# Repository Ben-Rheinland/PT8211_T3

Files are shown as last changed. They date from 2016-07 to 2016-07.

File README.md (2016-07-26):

# PT8211_T3
This is an adapter board ("shield") for the Teensy 3.x by PJRC.<br>
It features the cheap two-channel DAC PT8211 by Princeton Technology and adds a power supply filter, an analog third order low pass filter and output buffering.
<br>
https://forum.pjrc.com/threads/29284-Dual-channel-16bit-dac-PT8211

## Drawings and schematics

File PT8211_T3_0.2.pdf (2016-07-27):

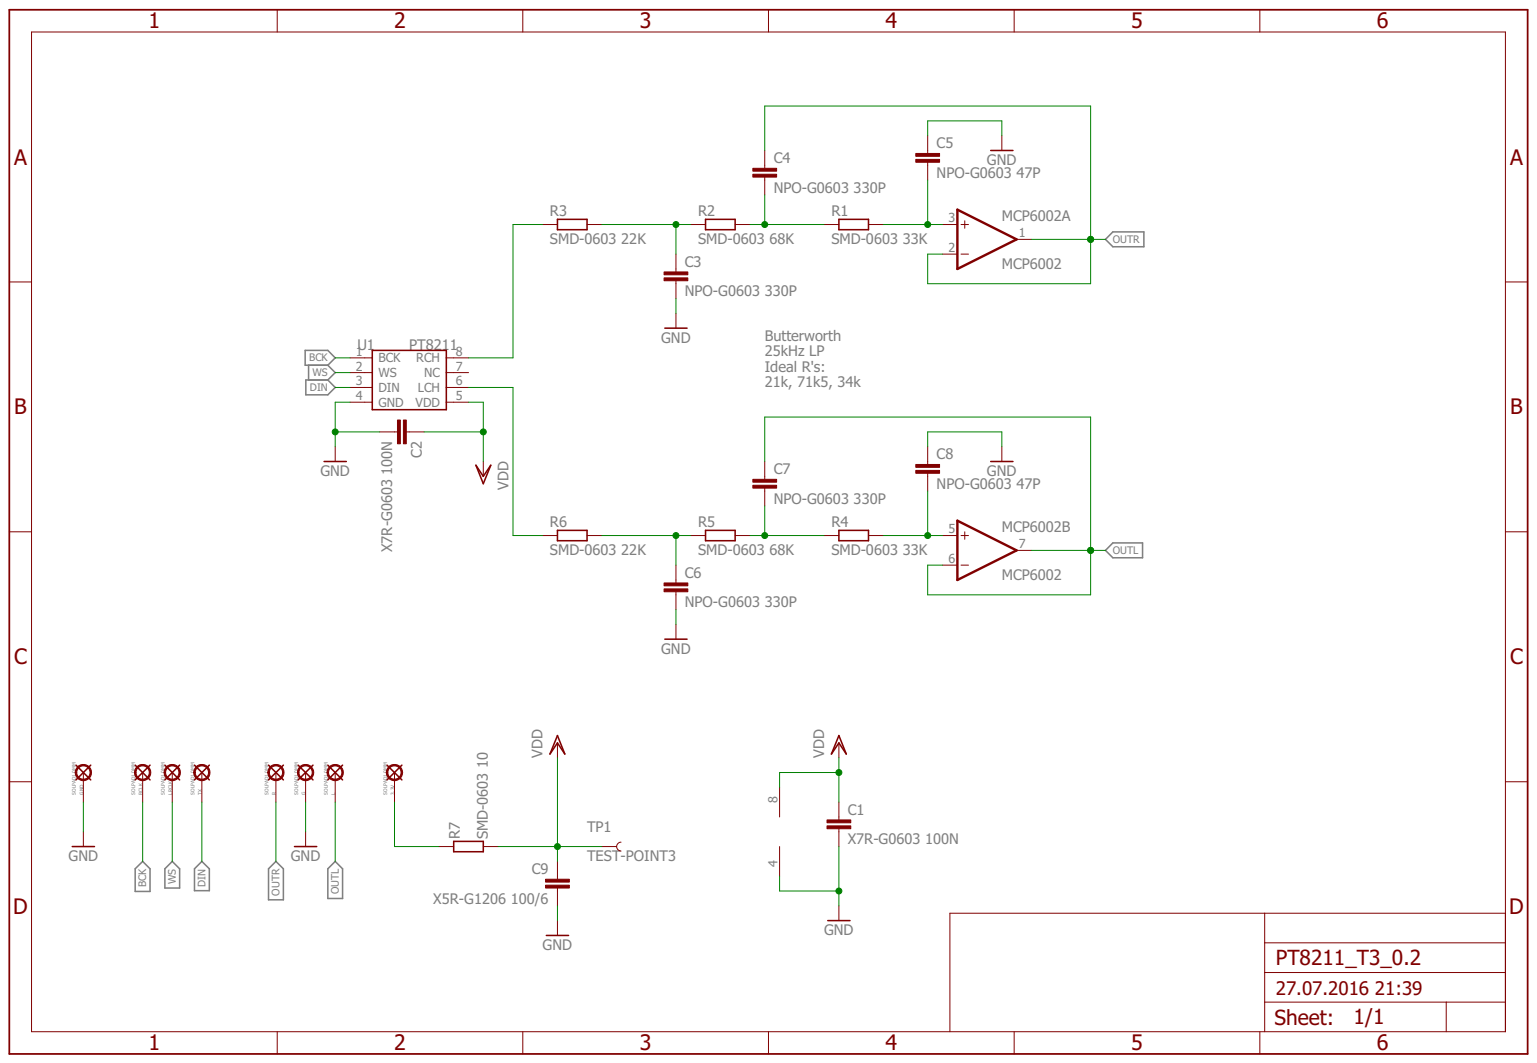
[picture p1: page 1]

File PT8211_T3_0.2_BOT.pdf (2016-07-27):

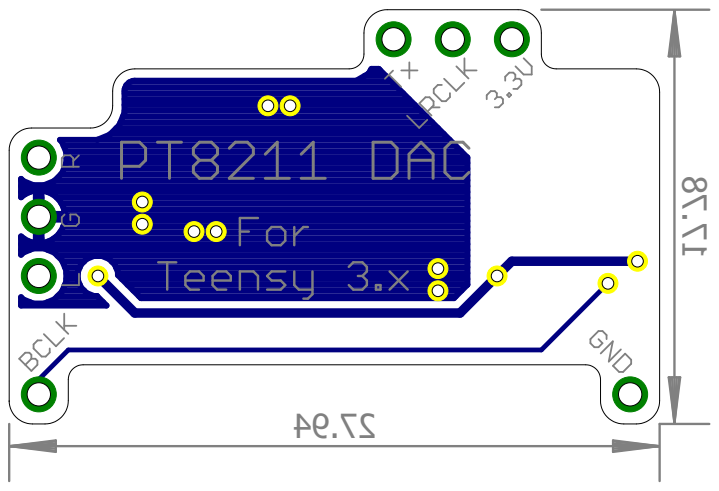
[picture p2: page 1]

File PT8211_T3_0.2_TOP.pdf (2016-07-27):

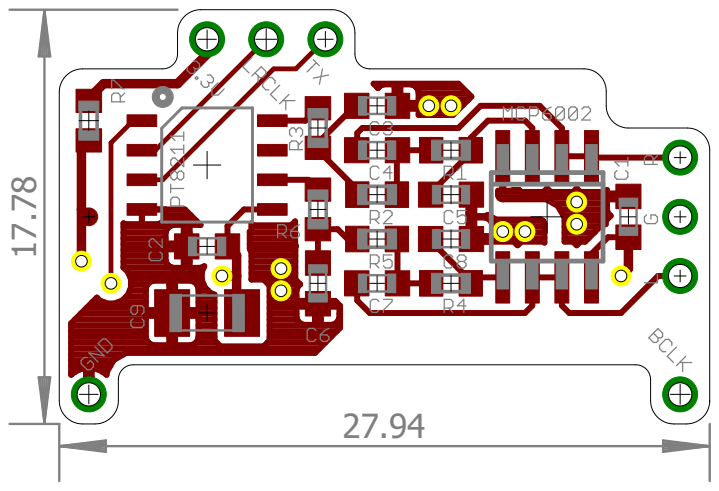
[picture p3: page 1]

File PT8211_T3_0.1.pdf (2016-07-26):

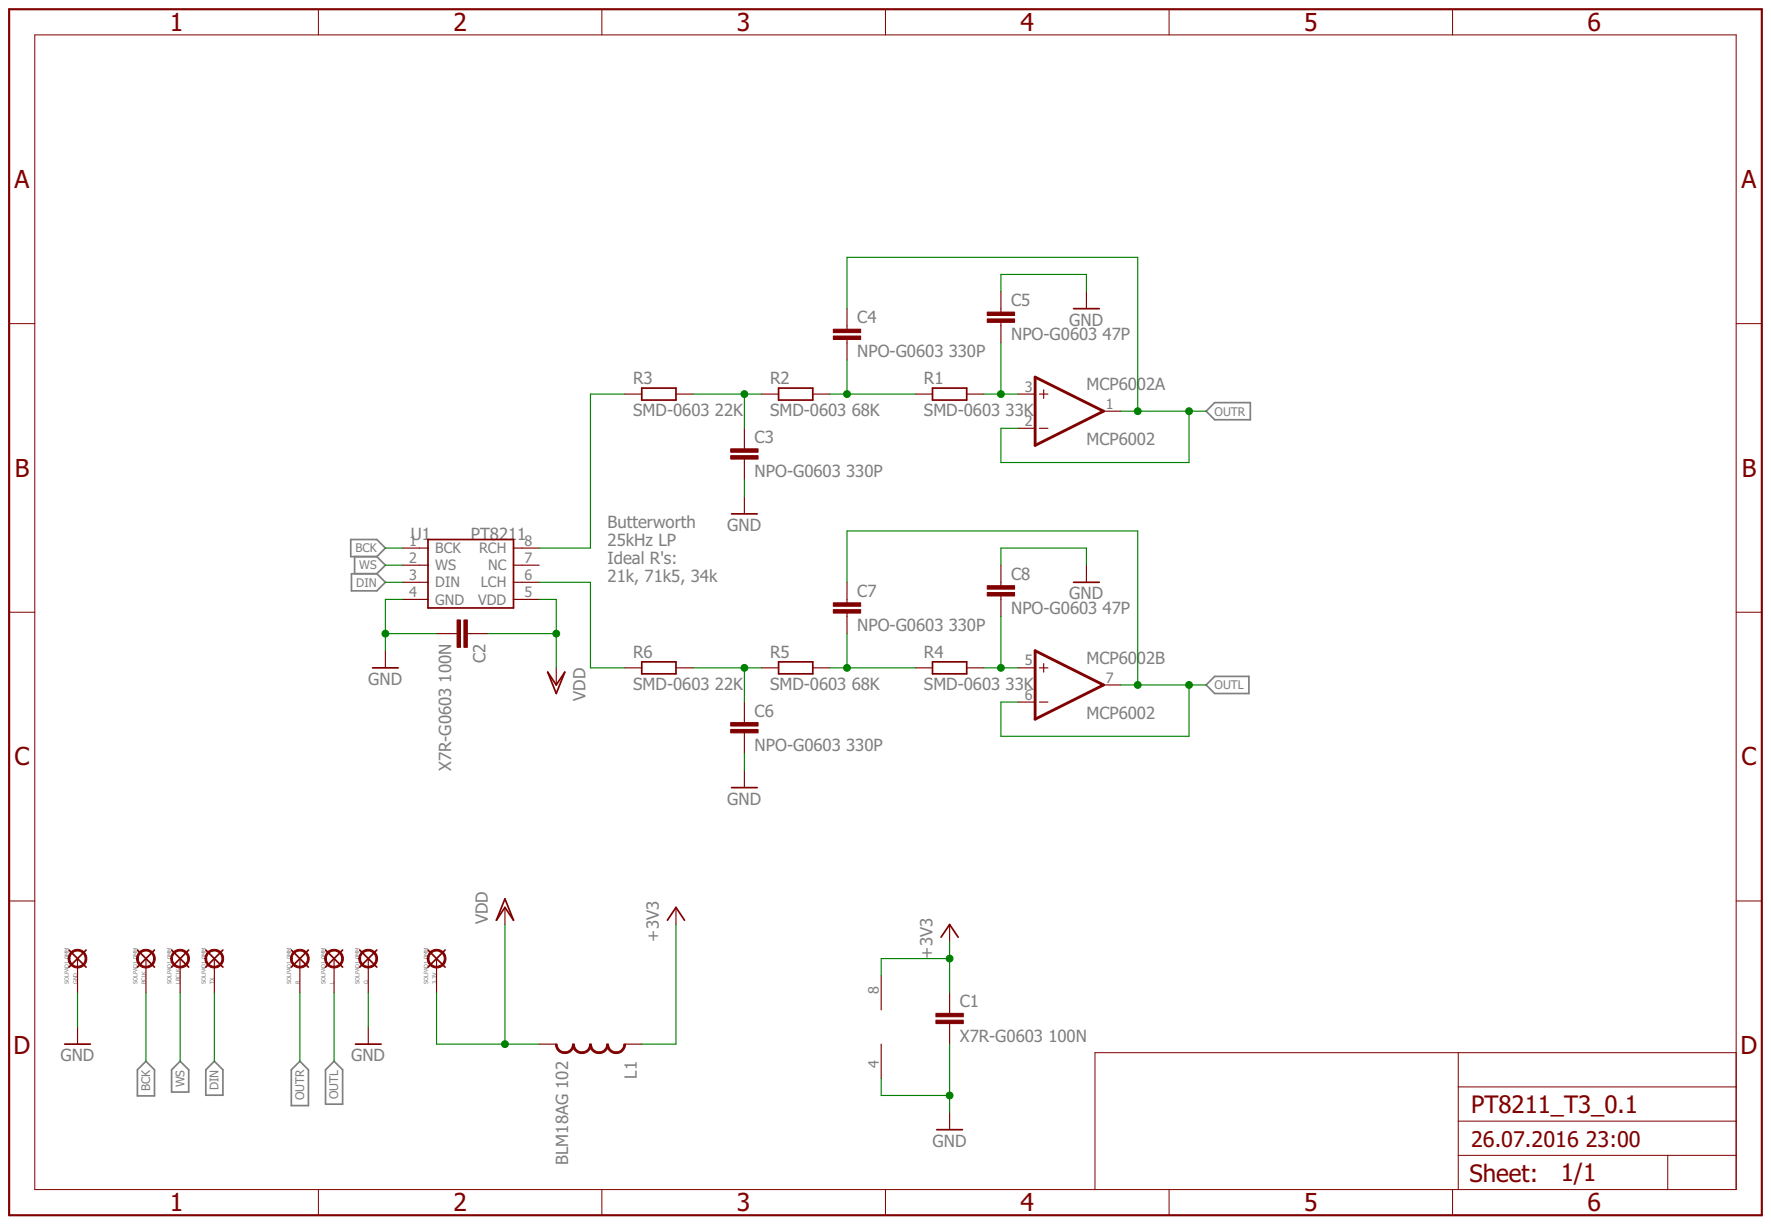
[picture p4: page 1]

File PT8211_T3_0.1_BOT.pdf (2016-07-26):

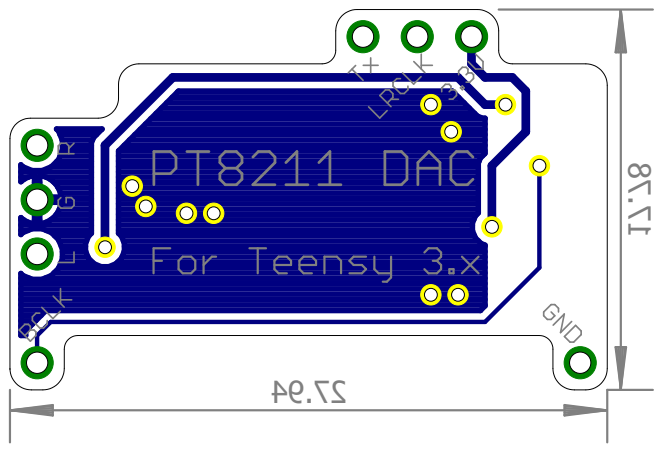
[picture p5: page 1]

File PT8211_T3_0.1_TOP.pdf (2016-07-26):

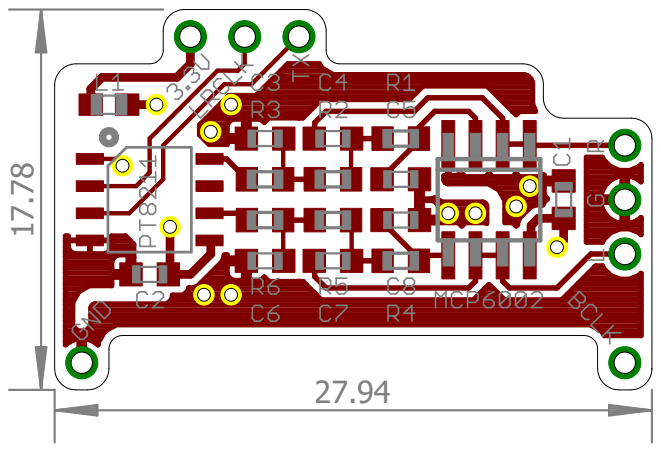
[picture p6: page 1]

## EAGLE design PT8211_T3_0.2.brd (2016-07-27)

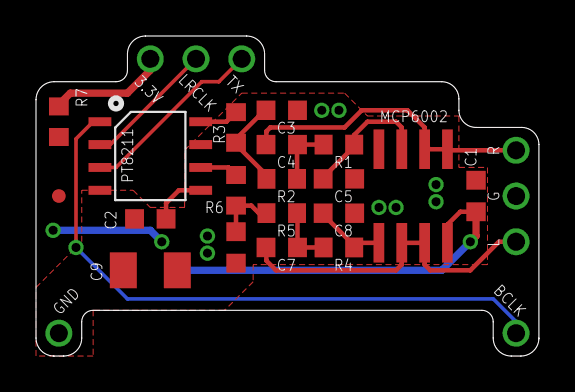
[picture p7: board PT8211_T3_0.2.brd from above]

Board: 2 copper layers, 27.9 x 17.8 mm, 27 parts (0 on the bottom side), 16 nets.

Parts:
3.3V: SOLPAD1,0MM; SOLPAD1MM
BCLK: SOLPAD1,0MM; SOLPAD1MM
C1, C2: X7R-G0603 100N; C0603K
C3, C4, C6, C7: NPO-G0603 330P; C0603K
C5, C8: NPO-G0603 47P; C0603K
C9: X5R-G1206 100/6; C1206K
G: SOLPAD1,0MM; SOLPAD1MM
GND: SOLPAD1,0MM; SOLPAD1MM
L: SOLPAD1,0MM; SOLPAD1MM
LRCLK: SOLPAD1,0MM; SOLPAD1MM
MCP6002: MCP6002; SO08
R: SOLPAD1,0MM; SOLPAD1MM
R1, R4: SMD-0603 33K; R0603
R2, R5: SMD-0603 68K; R0603
R3, R6: SMD-0603 22K; R0603
R7: SMD-0603 10; R0603
TP1: TEST-POINT3; PAD.03X.03
TX: SOLPAD1,0MM; SOLPAD1MM
U1: PT8211; SOP8-6.0-4.9X3.9

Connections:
BCK: BCLK.P$1, U1.1
DIN: TX.P$1, U1.3
GND: C1.2, C2.2, C3.2, C5.1, C6.2, C8.1, C9.2, G.P$1, GND.P$1, MCP6002.4, U1.4
unnamed: C6.1, R5.1, R6.2
unnamed: C7.2, R4.1, R5.2
unnamed: C8.2, MCP6002.5, R4.2
unnamed: C3.1, R2.1, R3.2
unnamed: C4.2, R1.1, R2.2
unnamed: C5.2, MCP6002.3, R1.2
unnamed: 3.3V.P$1, R7.1
unnamed: R6.1, U1.6
unnamed: R3.1, U1.8
OUTL: C7.1, L.P$1, MCP6002.6, MCP6002.7
OUTR: C4.1, MCP6002.1, MCP6002.2, R.P$1
VDD: C1.1, C2.1, C9.1, MCP6002.8, R7.2, U1.5
WS: LRCLK.P$1, U1.2

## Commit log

2016-07-26 First upload, V0.1
    [PT8211_T3_0.1.brd, PT8211_T3_0.1.sch]
2016-07-26 Add documentation PDFs
    [PT8211_T3_0.1.brd]
2016-07-27 Change supply voltage filter, re-route power rail,
    Supply voltage filtering now is an RC-filter with 10 Ohms, 100µF instead
    of ferrite and 2x 100nF
    [PT8211_T3_0.2.brd, PT8211_T3_0.2.sch]

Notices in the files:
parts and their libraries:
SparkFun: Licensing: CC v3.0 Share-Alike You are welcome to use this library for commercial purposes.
